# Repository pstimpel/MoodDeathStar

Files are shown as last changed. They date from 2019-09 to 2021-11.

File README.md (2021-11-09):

# MoodDeathStar
A moodlamp and a Death star once had a one night stand...

## Download Death Star stl
https://pinshape.com/items/30200-3d-printed-star-wars-death-star

## 3D Print the stuff
Using my Prusa I3Mk3 I printed the 2 shells in 0.15mm. The inlays were printed in 0.25mm. I was using filament from https://DasFilament.de. I used silver for the shells, and anthracite for the inlays. The housing for the electronics was printed in "nature", and once I ran out of this filament I was using some silver as well. I was printing the Death Star at 150% size. The electronic housing does not need any scaling.

## Buy the stuff you need (all Amazon links are non profit links and just examples for the stuff I bought)
1 switch, has to handle 3A or more https://www.amazon.de/gp/product/B012MCQ2QO

1 Arduino Nano 5V https://www.amazon.de/gp/product/B07H2VT2JN/

1m of RGB LEDs, you need around 40 LEDs https://www.amazon.de/gp/product/B01LSF4QDM

1 power adaptor to 5V DC, 3A https://www.amazon.de/gp/product/B07HSPT57Y

1 matching socket jack https://www.amazon.de/gp/product/B009PH1J5Y

1 USB mini extension 200mm https://www.amazon.de/gp/product/B01MUEAAF0

1 tactile button 6mm https://www.amazon.de/gp/product/B07Q1BXV7T/

2 screw terminals 5mm https://www.amazon.de/gp/product/B07K31L4FH

1 resistor 260 Ohm, 1/4 Watt

1 resistor 10 kOhm, 1/4 Watt

1 Potentiometer 4.7kOhm https://www.amazon.de/gp/product/B07MM4GPWC

3 2.54mm pin connectors https://www.amazon.de/gp/product/B06XR8CV8P

1 tripolar remale 2.54mm connector, like from a servo cable

some cable, has to handle 3A

some cable, doesn't have to handle 3A

a small piece of stripboard to mount the tactile button on it

## Create the PCB, or use a service to do so
Creating the PCB yourself is always fun. I was using toner transfer method, and the sponge method to remove copper from the PCB. If you dislike to work with chemicals, just order the PCB. You can find the layout inside the electronics folder. The layout was created using the famous and almighty KICAD (https://www.kicad.org/).

## Add the electronics to the housing
You need some M3x8mm screws to lock down the pcb, the delock connector, the trigger and the USB. The Tactile button goes a small stripboard piece. Just add two cables around 10cm length each to it, and connect the cables to one of the screw terminals on your main pcb. This while act as a trigger to switch between the different illunmination modes.

## Program your Arduino
Inside the Arduino folder there is an example. Nothing fancy, but maybe a start. The illumination was taken from the many examples they deliver with the FastLED library. I simply added some control for the trigger buttin ad the brightness adjusting potentiometer.

## Create the death star
We work from top to bottom. Add the first five inlayes (1, 2, 3 ,4 ,5) to the top shell - the one without an hole in the middle. In the inlays 6 to 31 add 4 holes using a 10mm drill, kind if a circle shape around the middle hole is our goal. Make sure the holes lines up, so you create kind of 4 channels for the led strips. Now create 4 strips of 10 LED each. Connect 2 strips using 5cm tripolar cable. The + and - cable has to handle 3A. The signal cable does not handle much current. Keep in mind the direction of the data signal. Usually these LED strips work in one direction, only.

    ---> data signal direction --->
    strip 1 --- 3 cable 5cm --- strip 2 --- 3 cable 5cm
    strip 3 --- 3 cable 5cm --- strip 4

Use inlay 6. Add the first pair of connected led strips to holes 1 and 2 - it does not matter if your count holes clockwise or counterclockwise, just stick with your decision. Add second pair of strips to holes 3 and 4. Now add inlay after inlay. After inlay 31 do not forget to add the collar from the death star STLs. Now cut the middle standoff from the botton half of the shell. Cut it so, that you do NOT cut into the mounting point on the bottom. Use some super glue to mount the cut standoff to the collar. Add Inlays 31 to around 10, do not forget to drill 4 holes into each of the inlays, as you did with the first half of the inlays. Once you approach the end of the led strips, use your solder iron again, and connect the the cable of strip 2 to strip 3. 

Drill a hole of 7mm onto the stand, and into the mounting point of the bottom half of your death star. Cut 2 pieces of 40 cm of cable from the 3A capable one, and another piece of 40 cm from your low current cable. Feed the 3 cables from the bottom through the stand, through the mounting hole of the lower death star half into the inner part of the death star. And th left inlays to the bottom half. Use some hot glue to fix them. Now solder the 3 cables to strip 1. Connect the other side of the cable to the servo like connector. 

Run a first test. Working well? Use some super glue to connect both halfs of your death star. Mount the "ball" on top of the stand. Use some super glue to fix it there. Use 2 M3-12mm screws, and mount the top stand to the bottom stand. There are holes you use, just use a longer screw driver and the holes on the bottom of your stand.

Brag with your new illuminated Death star.

Video explaining this project: https://youtu.be/01-m4wZ4NJw

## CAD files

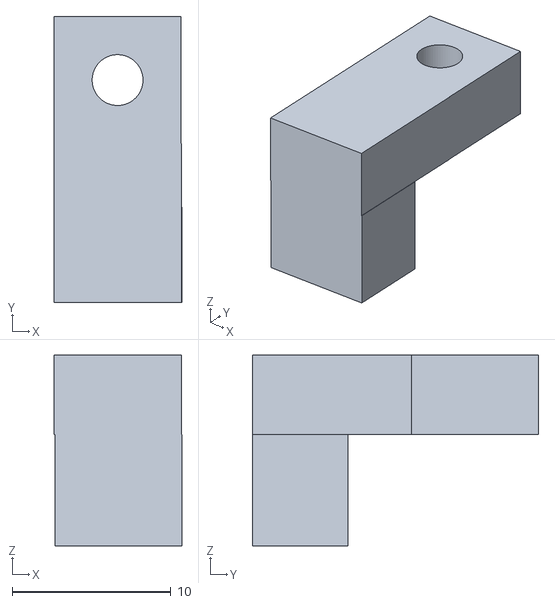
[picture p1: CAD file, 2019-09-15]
ElectronicsHousing/PlatineMainHolder.stl
8.05 x 18.0 x 12.0

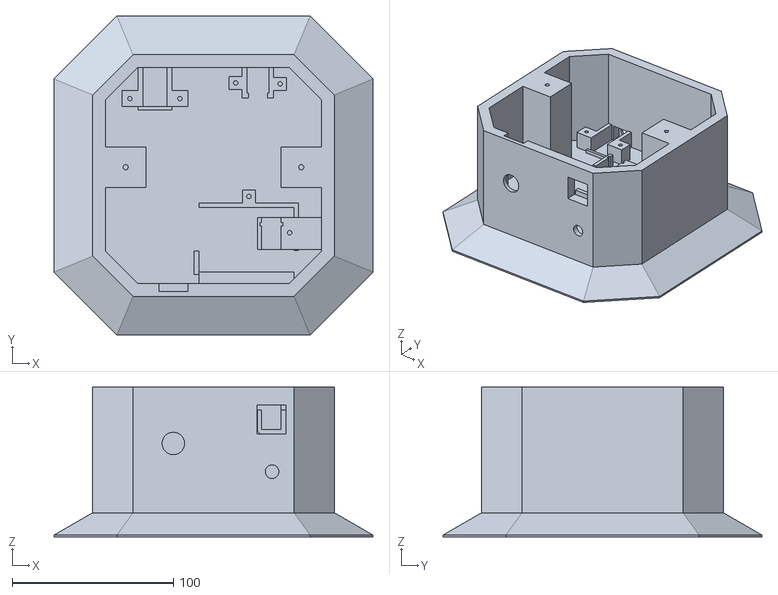
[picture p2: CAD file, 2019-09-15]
ElectronicsHousing/Bottom.stl
198.0 x 198.0 x 93.0

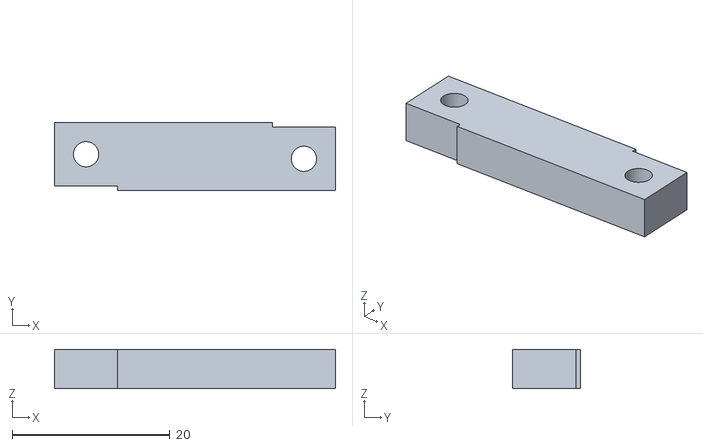
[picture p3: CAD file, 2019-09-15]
ElectronicsHousing/USBLock.stl
35.6 x 8.58 x 5.00

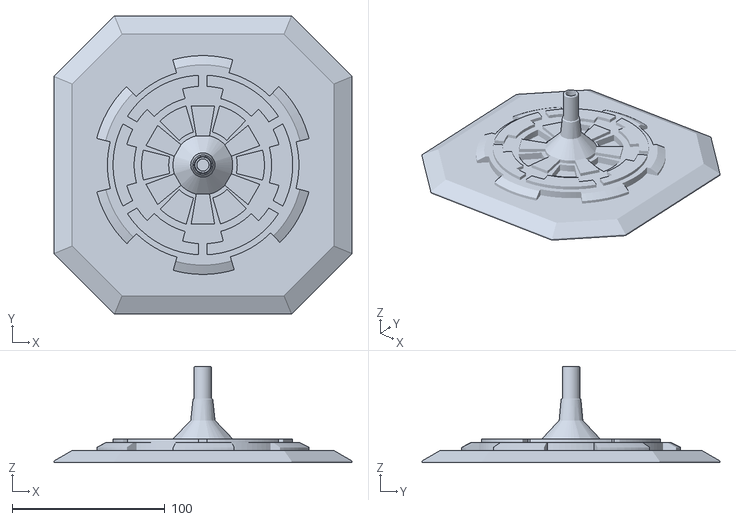
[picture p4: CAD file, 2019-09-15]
ElectronicsHousing/Top.stl
195.3 x 195.3 x 63.2

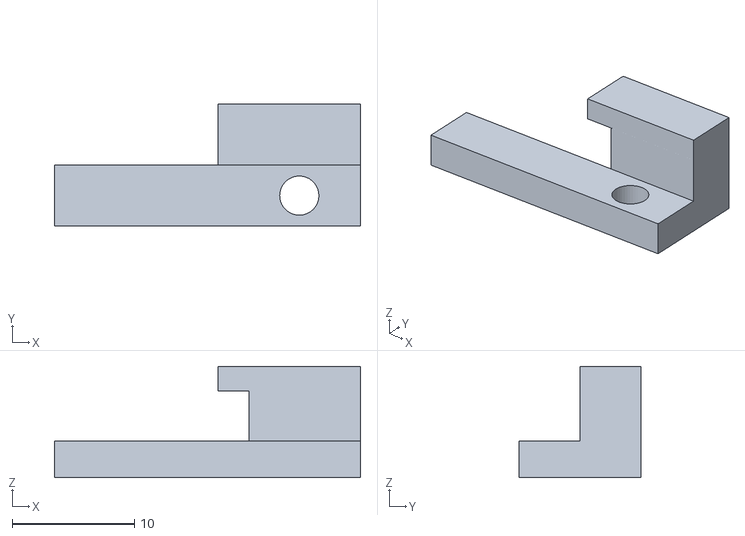
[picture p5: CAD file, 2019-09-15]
ElectronicsHousing/TriggerLock.stl
25.0 x 10.0 x 9.10

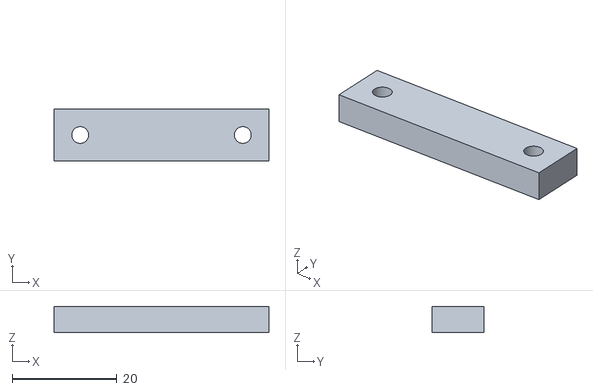
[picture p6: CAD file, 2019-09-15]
ElectronicsHousing/PlugLock.stl
41.0 x 10.0 x 5.00

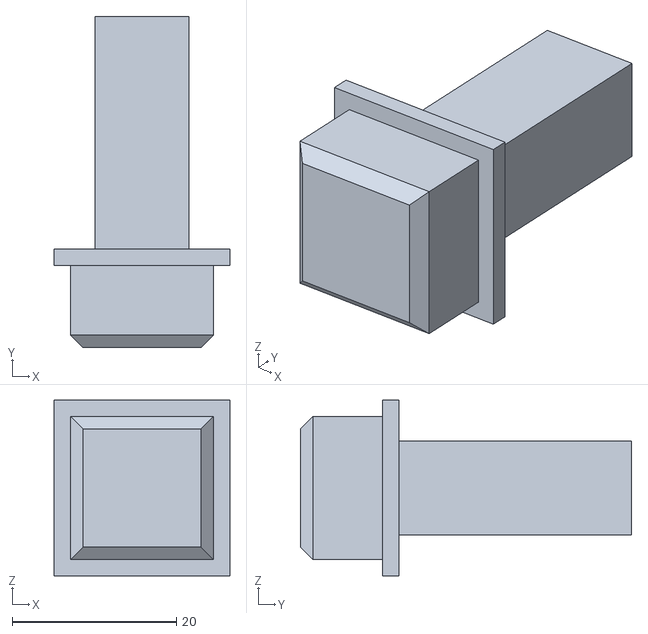
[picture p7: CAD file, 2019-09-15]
ElectronicsHousing/Trigger.stl
21.4 x 40.3 x 21.4

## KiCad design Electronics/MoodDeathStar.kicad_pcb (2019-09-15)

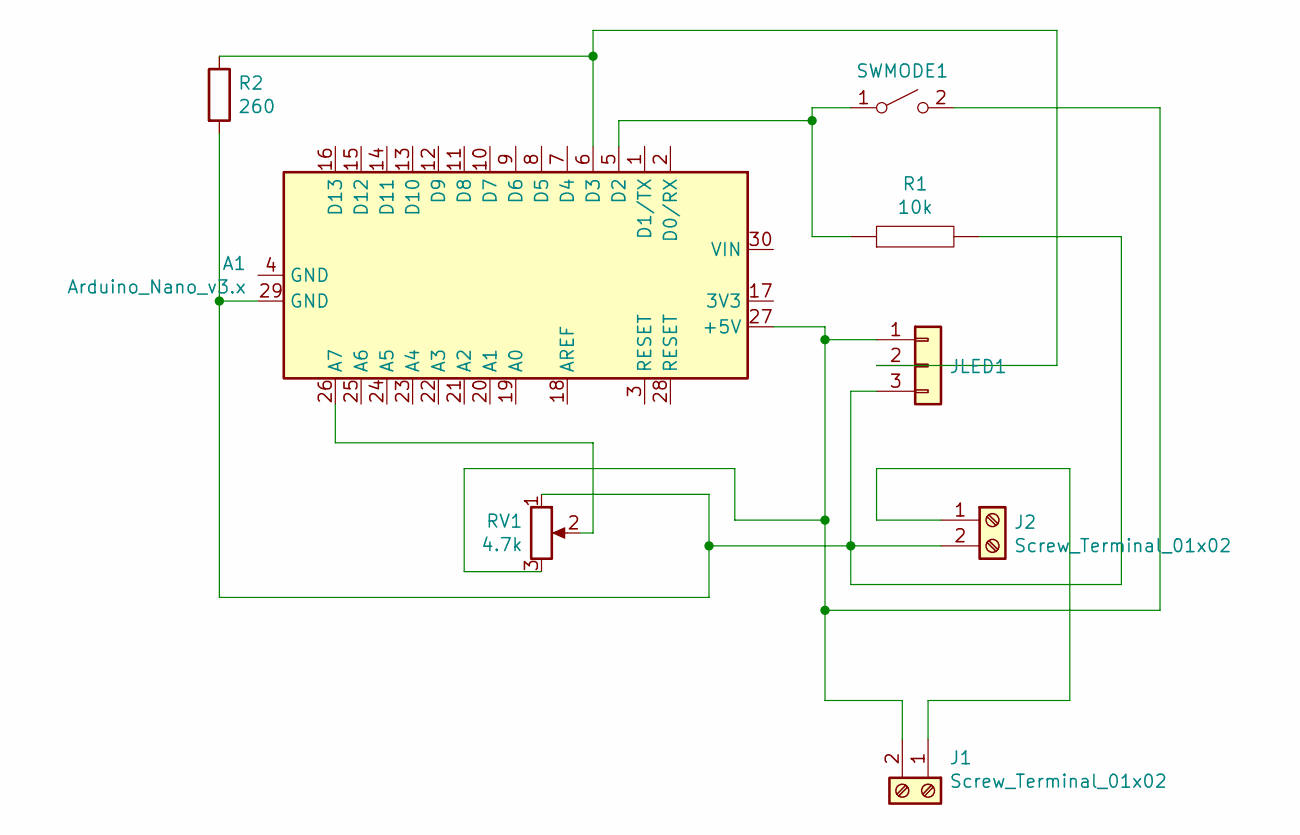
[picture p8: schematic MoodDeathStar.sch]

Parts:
A1: Arduino_Nano_v3.x; Arduino_Nano
J1, J2: Screw_Terminal_01x02; TerminalBlock_Altech_AK300-2_P5.00mm
JLED1: Conn_01x03; PinHeader_1x03_P2.54mm_Vertical
R1: 10k; R_Axial_DIN0204_L3.6mm_D1.6mm_P7.62mm_Horizontal
R2: 260; R_Axial_DIN0204_L3.6mm_D1.6mm_P7.62mm_Horizontal
RV1: 4.7k; Potentiometer_Alps_RK163_Single_Horizontal
SWMODE1: s; PinHeader_1x02_P2.54mm_Vertical

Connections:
unnamed: A1.5 (D2), R1.1, SWMODE1.1 (A)
unnamed: A1.6 (D3), JLED1.2, R2.1
unnamed: A1.26 (A7), RV1.2
unnamed: A1.27 (+5V), J1.2, JLED1.1, RV1.3, SWMODE1.2 (B)
unnamed: A1.29 (GND), J2.2, JLED1.3, R1.2, R2.2, RV1.1
unnamed: J1.1, J2.1

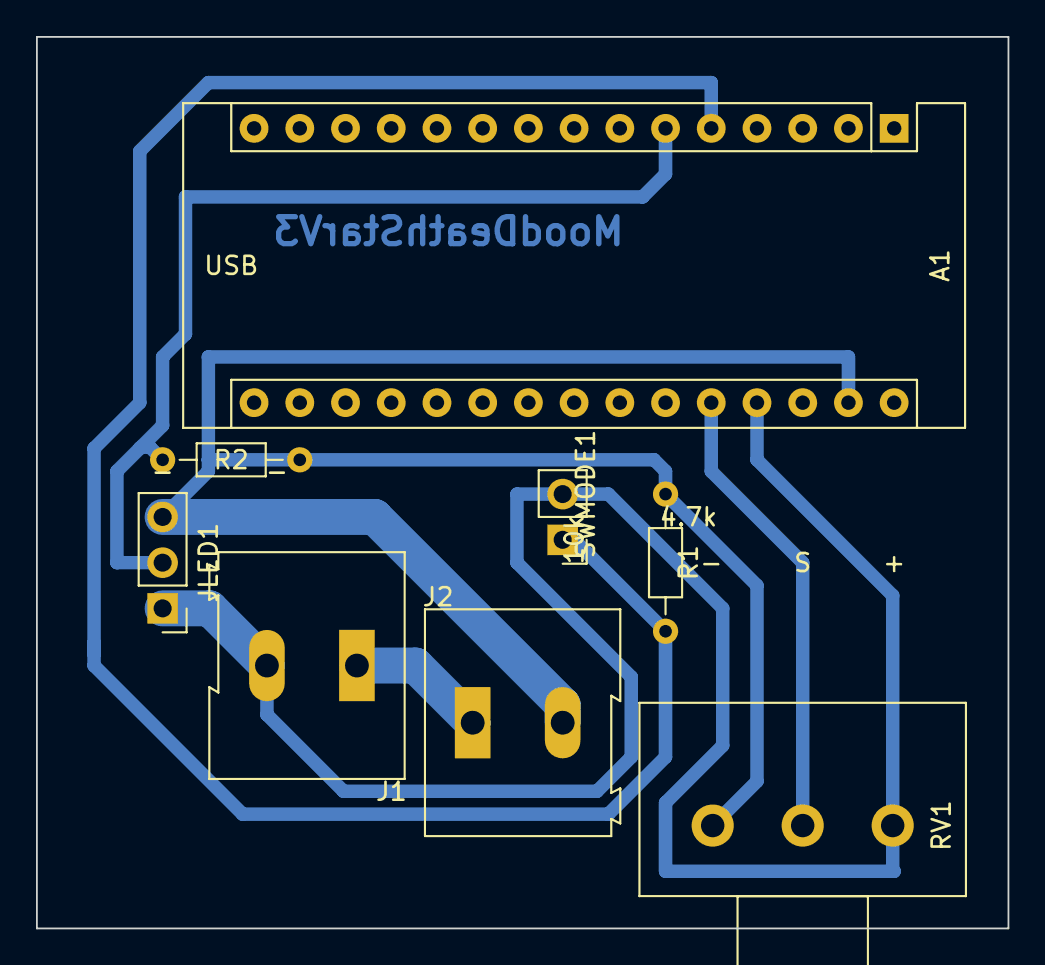
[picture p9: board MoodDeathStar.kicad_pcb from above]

Board: 2 copper layers, 54.0 x 49.5 mm, 8 parts (0 on the bottom side), 6 nets.

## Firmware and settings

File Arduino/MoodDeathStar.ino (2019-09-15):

#include <FastLED.h>

FASTLED_USING_NAMESPACE

#if defined(FASTLED_VERSION) && (FASTLED_VERSION < 3001000)
#warning "Requires FastLED 3.1 or later; check github for latest code."
#endif

#define DATA_PIN    3
//#define CLK_PIN   4
#define LED_TYPE    WS2811
#define COLOR_ORDER GRB
#define NUM_LEDS    40
CRGB leds[NUM_LEDS];
CRGBPalette16 gPal;
bool gReverseDirection = false;
#define FRAMES_PER_SECOND  120
volatile int brightness = 96;
int oldbrightness= 0;

volatile bool glowstate = false;

volatile bool triggerInUse=false;

volatile bool firstrun=true;

void setup() {
  Serial.begin(9600); //init debug console 
  
  delay(500); // 500 milliseconds delay for recovery
  pinMode(2, INPUT); //modeswitch
  // tell FastLED about the LED strip configuration
  FastLED.addLeds<LED_TYPE,DATA_PIN,COLOR_ORDER>(leds, NUM_LEDS).setCorrection(TypicalLEDStrip);
  //FastLED.addLeds<LED_TYPE,DATA_PIN,CLK_PIN,COLOR_ORDER>(leds, NUM_LEDS).setCorrection(TypicalLEDStrip);

  // set master brightness control
  FastLED.setBrightness(brightness);

  gPal = HeatColors_p;
}


// List of patterns to cycle through.  Each is defined as a separate function below.
typedef void (*SimplePatternList[])();
SimplePatternList gPatterns = { upanddownDarkRed, upanddown, bpm, glow, allwhite, flicker, rainbow, rainbowWithGlitter, confetti, sinelon, juggle, Fire2012WithPalette };

uint8_t gCurrentPatternNumber = 0; // Index number of which pattern is current
uint8_t gHue = 0; // rotating "base color" used by many of the patterns
  
void loop()
{
  
  
  int potiValue = analogRead(A7);//read poti, 0-1023  float voltage = sensorValue * (5.0 / 1023.0);

  brightness = map(potiValue, 0, 1023, 0, 255); //map the poti value to brightness
  if(brightness < 5) {
    brightness=0;
  }
  if(brightness > 250) {
    brightness=255;
  }
  if( (oldbrightness < brightness-3) || (oldbrightness > brightness+3) || firstrun==true) {
    if(firstrun==true) {
      firstrun=false;
      Serial.println("first run correction after switching on");
    }
    Serial.print("Brightness:");
    Serial.println(brightness);
    oldbrightness=brightness;
    FastLED.setBrightness(brightness);
  }
  // Call the current pattern function once, updating the 'leds' array
  gPatterns[gCurrentPatternNumber]();

  // send the 'leds' array out to the actual LED strip
  FastLED.show();  
  // insert a delay to keep the framerate modest
  FastLED.delay(1000/FRAMES_PER_SECOND); 

  // do some periodic updates
  EVERY_N_MILLISECONDS( 20 ) { gHue++; } // slowly cycle the "base color" through the rainbow
  //EVERY_N_SECONDS( 10 ) { nextPattern(); } // change patterns periodically
  if(digitalRead(2) == HIGH) {
    if(triggerInUse==false) {  
      Serial.println("------------>trigger");  
      nextPattern();
      triggerInUse=true;
    }
      
  } else {
    if(triggerInUse==true) {
      triggerInUse=false;
    }
  }
}

#define ARRAY_SIZE(A) (sizeof(A) / sizeof((A)[0]))


void nextPattern()
{
  //reset brightness to potivalue
  FastLED.setBrightness(brightness);
  // add one to the current pattern number, and wrap around at the end
  gCurrentPatternNumber = (gCurrentPatternNumber + 1) % ARRAY_SIZE( gPatterns);
  Serial.print("PATTERN: ");
  Serial.println(gCurrentPatternNumber);
}


void upanddownDarkRed(){
  CRGB thiscolor = CRGB::DarkRed;
  for(int i = 1; i < 9;i++) {
      for( int i = 0; i < NUM_LEDS; i++) { //9948
        leds[i] = CRGB::Black;
      }
      int reverse = 0 - i;

      leds[i-1] = thiscolor;
      leds[i] = thiscolor;
      leds[i+1] = thiscolor;
      
      leds[19+reverse-1] = thiscolor;      
      leds[19+reverse] = thiscolor;      
      leds[19+reverse+1] = thiscolor;      
      
      leds[20+i-1] = thiscolor;
      leds[20+i] = thiscolor;
      leds[20+i+1] = thiscolor;
      
      leds[39+reverse-1] = thiscolor;
      leds[39+reverse] = thiscolor;
      leds[39+reverse+1] = thiscolor;
      
      FastLED.show();  
      delay(150);
  }
  for(int i = 8; i >= 1;i--) {
      for( int i = 0; i < NUM_LEDS; i++) { //9948
        leds[i] = CRGB::Black;
      }
      int reverse = 0 - i;
      
      leds[i-1] = thiscolor;
      leds[i] = thiscolor;
      leds[i+1] = thiscolor;
      
      leds[19+reverse-1] = thiscolor;      
      leds[19+reverse] = thiscolor;      
      leds[19+reverse+1] = thiscolor;      
      
      leds[20+i-1] = thiscolor;
      leds[20+i] = thiscolor;
      leds[20+i+1] = thiscolor;
      
      leds[39+reverse-1] = thiscolor;
      leds[39+reverse] = thiscolor;
      leds[39+reverse+1] = thiscolor;
      
      FastLED.show();  
      delay(150);
  }
    
}


void upanddown(){
  int colorint = random(1,8);
  CRGB thiscolor = CRGB::White;
  switch (colorint) {
    case 1:
      thiscolor = CRGB::White;
      break;
    case 2:
      thiscolor = CRGB::Blue;
      break;
    case 3:
      thiscolor = CRGB::Yellow;
      break;
    case 4:
      thiscolor = CRGB::Red;
      break;
    case 5:
      thiscolor = CRGB::Green;
      break;
    case 6:
      thiscolor = CRGB::Pink;
      break;
    case 7:
      thiscolor = CRGB::Brown;
      break;
    case 8:
      thiscolor = CRGB::DarkBlue;
      break;
    default:
      break;
  }
  for(int i = 1; i < 9;i++) {
      for( int i = 0; i < NUM_LEDS; i++) { //9948
        leds[i] = CRGB::Black;
      }
      int reverse = 0 - i;

      leds[i-1] = thiscolor;
      leds[i] = thiscolor;
      leds[i+1] = thiscolor;
      
      leds[19+reverse-1] = thiscolor;      
      leds[19+reverse] = thiscolor;      
      leds[19+reverse+1] = thiscolor;      
      
      leds[20+i-1] = thiscolor;
      leds[20+i] = thiscolor;
      leds[20+i+1] = thiscolor;
      
      leds[39+reverse-1] = thiscolor;
      leds[39+reverse] = thiscolor;
      leds[39+reverse+1] = thiscolor;
      
      FastLED.show();  
      delay(100);
  }
  for(int i = 8; i >= 1;i--) {
      for( int i = 0; i < NUM_LEDS; i++) { //9948
        leds[i] = CRGB::Black;
      }
      int reverse = 0 - i;
      
      leds[i-1] = thiscolor;
      leds[i] = thiscolor;
      leds[i+1] = thiscolor;
      
      leds[19+reverse-1] = thiscolor;      
      leds[19+reverse] = thiscolor;      
      leds[19+reverse+1] = thiscolor;      
      
      leds[20+i-1] = thiscolor;
      leds[20+i] = thiscolor;
      leds[20+i+1] = thiscolor;
      
      leds[39+reverse-1] = thiscolor;
      leds[39+reverse] = thiscolor;
      leds[39+reverse+1] = thiscolor;
      
      FastLED.show();  
      delay(100);
  }
    
}

void glow() {

      for( int i = 0; i < NUM_LEDS; i=i+3) { //9948
        leds[i] = CRGB::White;
      }
      
      if(glowstate==false) {
        glowstate=true;
        for(int i=10;i<brightness;i=i+10) {
          FastLED.setBrightness(i);
          FastLED.show();  
          delay(30);
        }
        
      } else {
        glowstate=false;
        for(int i=brightness;i>=0;i=i-10) {
          FastLED.setBrightness(i);
          FastLED.show();  
          delay(30);
        }
        
      }
      //delay(1000); 
}


void allwhite() {
      for( int i = 0; i < NUM_LEDS; i=i+3) { //9948
        leds[i] = CRGB::Black;
      }
      FastLED.show();  
      delay(5);
      for( int i = 0; i < NUM_LEDS; i=i+3) { //9948
        leds[i] = CRGB::White;
      }
      FastLED.show();  
      delay(100);
       
}

void flicker()
{

  int result = random(1, 7);
  switch (result) {
    case 1:
      for( int i = 0; i < NUM_LEDS; i=i+3) { //9948
        leds[i] = CRGB::White;
      }
      for( int i = 1; i < NUM_LEDS; i=i+3) { //9948
        leds[i] = CRGB::Blue;
      }
      for( int i = 2; i < NUM_LEDS; i=i+3) { //9948
        leds[i] = CRGB::Red;
      }
      break;
    case 2:
      for( int i = 0; i < NUM_LEDS; i=i+3) { //9948
        leds[i] = CRGB::Yellow;
      }
      for( int i = 1; i < NUM_LEDS; i=i+3) { //9948
        leds[i] = CRGB::DarkRed;
      }
      for( int i = 2; i < NUM_LEDS; i=i+3) { //9948
        leds[i] = CRGB::Green;
      }
      break;
    case 3:
      for( int i = 0; i < NUM_LEDS; i=i+3) { //9948
        leds[i] = CRGB::DarkRed;
      }
      for( int i = 1; i < NUM_LEDS; i=i+3) { //9948
        leds[i] = CRGB::DarkBlue;
      }
      for( int i = 2; i < NUM_LEDS; i=i+3) { //9948
        leds[i] = CRGB::Yellow;
      }
      break;
    case 4:
      for( int i = 0; i < NUM_LEDS; i=i+3) { //9948
        leds[i] = CRGB::Cornsilk;
      }
      for( int i = 1; i < NUM_LEDS; i=i+3) { //9948
        leds[i] = CRGB::DeepPink;
      }
      for( int i = 2; i < NUM_LEDS; i=i+3) { //9948
        leds[i] = CRGB::White;
      }
      break;
    case 5:
      for( int i = 0; i < NUM_LEDS; i=i+3) { //9948
        leds[i] = CRGB::White;
      }
      for( int i = 1; i < NUM_LEDS; i=i+3) { //9948
        leds[i] = CRGB::White;
      }
      for( int i = 2; i < NUM_LEDS; i=i+3) { //9948
        leds[i] = CRGB::White;
      }
      break;
    case 6:
      for( int i = 0; i < NUM_LEDS; i=i+3) { //9948
        leds[i] = CRGB::Blue;
      }
      for( int i = 1; i < NUM_LEDS; i=i+3) { //9948
        leds[i] = CRGB::Blue;
      }
      for( int i = 2; i < NUM_LEDS; i=i+3) { //9948
        leds[i] = CRGB::Blue;
      }
      break;
    case 7:
      for( int i = 0; i < NUM_LEDS; i=i+3) { //9948
        leds[i] = CRGB::Red;
      }
      for( int i = 1; i < NUM_LEDS; i=i+3) { //9948
        leds[i] = CRGB::White;
      }
      for( int i = 2; i < NUM_LEDS; i=i+3) { //9948
        leds[i] = CRGB::Blue;
      }
      break;
    
    default:
      // statements
      break;
  }
  
  
  addGlitter(80);
  delay(10);
  
}

void rainbow() 
{
  // FastLED's built-in rainbow generator
  fill_rainbow( leds, NUM_LEDS, gHue, 7);
}

void rainbowWithGlitter() 
{
  // built-in FastLED rainbow, plus some random sparkly glitter
  rainbow();
  addGlitter(80);
}

void addGlitter( fract8 chanceOfGlitter) 
{
  if( random8() < chanceOfGlitter) {
    leds[ random16(NUM_LEDS) ] += CRGB::White;
  }
}

void confetti() 
{
  // random colored speckles that blink in and fade smoothly
  fadeToBlackBy( leds, NUM_LEDS, 10);
  int pos = random16(NUM_LEDS);
  leds[pos] += CHSV( gHue + random8(64), 200, 255);
}

void sinelon()
{
  // a colored dot sweeping back and forth, with fading trails
  fadeToBlackBy( leds, NUM_LEDS, 20);
  int pos = beatsin16( 13, 0, NUM_LEDS-1 );
  leds[pos] += CHSV( gHue, 255, 192);
}

void bpm()
{
  // colored stripes pulsing at a defined Beats-Per-Minute (BPM)
  uint8_t BeatsPerMinute = 62;
  CRGBPalette16 palette = PartyColors_p;
  uint8_t beat = beatsin8( BeatsPerMinute, 64, 255);
  for( int i = 0; i < NUM_LEDS; i++) { //9948
    leds[i] = ColorFromPalette(palette, gHue+(i*2), beat-gHue+(i*10));
  }
}

void juggle() {
  // eight colored dots, weaving in and out of sync with each other
  fadeToBlackBy( leds, NUM_LEDS, 20);
  byte dothue = 0;
  for( int i = 0; i < 8; i++) {
    leds[beatsin16( i+7, 0, NUM_LEDS-1 )] |= CHSV(dothue, 200, 255);
    dothue += 32;
  }
}

// Fire2012 by Mark Kriegsman, July 2012
// as part of "Five Elements" shown here: http://youtu.be/knWiGsmgycY
//// 
// This basic one-dimensional 'fire' simulation works roughly as follows:
// There's a underlying array of 'heat' cells, that model the temperature
// at each point along the line.  Every cycle through the simulation, 
// four steps are performed:
//  1) All cells cool down a little bit, losing heat to the air
//  2) The heat from each cell drifts 'up' and diffuses a little
//  3) Sometimes randomly new 'sparks' of heat are added at the bottom
//  4) The heat from each cell is rendered as a color into the leds array
//     The heat-to-color mapping uses a black-body radiation approximation.
//
// Temperature is in arbitrary units from 0 (cold black) to 255 (white hot).
//
// This simulation scales it self a bit depending on NUM_LEDS; it should look
// "OK" on anywhere from 20 to 100 LEDs without too much tweaking. 
//
// I recommend running this simulation at anywhere from 30-100 frames per second,
// meaning an interframe delay of about 10-35 milliseconds.
//
// Looks best on a high-density LED setup (60+ pixels/meter).
//
//
// There are two main parameters you can play with to control the look and
// feel of your fire: COOLING (used in step 1 above), and SPARKING (used
// in step 3 above).
//
// COOLING: How much does the air cool as it rises?
// Less cooling = taller flames.  More cooling = shorter flames.
// Default 55, suggested range 20-100 
#define COOLING  55

// SPARKING: What chance (out of 255) is there that a new spark will be lit?
// Higher chance = more roaring fire.  Lower chance = more flickery fire.
// Default 120, suggested range 50-200.
#define SPARKING 120


void Fire2012WithPalette()
{
// Array of temperature readings at each simulation cell
  static byte heat[NUM_LEDS];

  // Step 1.  Cool down every cell a little
    for( int i = 0; i < NUM_LEDS; i++) {
      heat[i] = qsub8( heat[i],  random8(0, ((COOLING * 10) / NUM_LEDS) + 2));
    }
  
    // Step 2.  Heat from each cell drifts 'up' and diffuses a little
    for( int k= NUM_LEDS - 1; k >= 2; k--) {
      heat[k] = (heat[k - 1] + heat[k - 2] + heat[k - 2] ) / 3;
    }
    
    // Step 3.  Randomly ignite new 'sparks' of heat near the bottom
    if( random8() < SPARKING ) {
      int y = random8(7);
      heat[y] = qadd8( heat[y], random8(160,255) );
    }

    // Step 4.  Map from heat cells to LED colors
    for( int j = 0; j < NUM_LEDS; j++) {
      // Scale the heat value from 0-255 down to 0-240
      // for best results with color palettes.
      byte colorindex = scale8( heat[j], 240);
      CRGB color = ColorFromPalette( gPal, colorindex);
      int pixelnumber;
      if( gReverseDirection ) {
        pixelnumber = (NUM_LEDS-1) - j;
      } else {
        pixelnumber = j;
      }
      leds[pixelnumber] = color;
    }
}

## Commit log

2019-09-15 Initial Added STL files Added circuit layout and pcb
    [Bottom.stl, MoodDeathStar.kicad_pcb, MoodDeathStar.sch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]
2019-09-15 Finalize readme and add Arduino stuff
